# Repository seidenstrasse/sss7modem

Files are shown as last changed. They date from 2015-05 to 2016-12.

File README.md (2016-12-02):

SSS7 Modems
===========
SSS7 is the **S**eidenstrasse **S**ignaling **S**ystem 7.

**This is still work in progress, contact me before building hardware !**

This repository contains the schematics its the hardware,
along with a description of the physical layer and the transport layer.
The actual application layer is developed independently of this project.

Physical Layer
--------------
The physical layer is based on a RS485-like two wire bus
(normal RS485 has different levels when idle),
using the *MCP2551* is used as transceiver chip.
Since this chip is actually a CAN-transceiver,
it has a well defined behaviour in case of collisions
and it allows to read back the bits which were actually on the bus while sending.
For regular RS485 transceivers a collision on the bus results
in one transceiver pulling the bus while the other one pulls it high,
effectively creating a temporary short circuit.
Therefore using a CAN-transceiver is preferable for our bus configuration.

The MCP2551 requires that the levels of the differential data lines are within +-7V
of its ground potential.
This a bit of a problem, since it is not really practical to run an additional wire
along the bus to provide a common ground.
Additionally routers may use power supplies which do not have a floating ground potential
(e.g. a computer power supply).
Connecting the ground rails of two non-floating power supplies will lead to a problems.
Therefore an isolated DC/DC converter is used to provide a floating supply voltage
for the transceiver chip and the data lines are isolated using optocouplers.
Still a common ground potential for all nodes is required for the transceiver chips to work.
This is solved by adding diodes in blocking direction between the floating 5v rail and both data lines
and between the chips ground and both data lines.
If the potential of the high data line is more than 0.7v above the floating 5v rail,
on of diodes will become conducting effectively shifting the floating grounds potential up.
Likewise if the potential of the low data line is more than 0.7v below the floating ground rail,
the ground rail will be shifted down.
Hence the floating grounds rails of all modems connected to bus will be within +-0.7v
relative to each other(not considering the voltage drop over the long wires).

Additionally these diodes suppress voltages spikes on the bus,
protecting the transceiver.

Using a sss7modem any device with a decent UART (microcontroller, raspi ...)
can communicate over long distances (1000m+).
The data is send at 9600 Baud (aka. 9,6kbit/s) with a maximum baudrate error of +-5%,
to ensure that even the slowest microcontroller can participate in the communication.
A slow bitrate also necessary to keep communication and collision detection reliable over longer
distances and allows to use slower (and cheaper) optocouplers.

Transport Layer
---------------

### Frame format:
``` 0xAA 0xFE <payload 16 bytes> <payload crc 1byte> ```

19 bytes total

**Header: 0xAA 0xFE**
- Choosen emperically to help the Uarts to synchronize
- Improves detection of two headers colliding

**CRC-Type: Maxim iButton 8-bit**
Polynomial: x^8 + x^5 + x^4 + 1 (0x8C)
Initial value: 0x0

### Communication Protocol

- **Not final, use with caution**
- Frames are sent using standard RS232 Uarts connected to sss7 modems
- Uarts should be configured to: 9600baud, 8bits, 1 stop bit, no flow-control, no parity
- Every node can send a frame at an arbitrary point in time,
    unless it is currently receiving a frame.
- Collision detection on the sender side is done by reading back each sent byte.
- Collision checking on receiver side, is done by checking the CRC and frame header.
- If a frame has been started and there are no new bytes received for 50ms,
    the frame is considered timed out and all received data can be dropped.
- Incoming messages are stored in a fifo until the application retrieves them.
- The receive fifo has a size of at least 2 messages.
- If the fifo is full all new messages will be dropped until messages are retrieved from the fifo.
    It is up to the application to retrieve message in time.
- Even if sending was successful, there is still a chance that the receiver could not
    receive the frame due to missing buffer space or not enough processing time to react.
    **Important messages should utilize a ack-mechanism.**
- It is up to the application to resend messages in case of a collision/missing ack.

### Planned API
- **Not final, use with caution**
- All calls are non-blocking,
    any real work should be done by ISRs or an eventloop, which is called periodically.

- **sss7_can_send()**

    Checks wether we see the bus as idle.
    Return true iff. we neither are currently receiving a frame
    nor are sending a frame of our own.

- **sss7_send_failed()**

    Checks the send error flag.
    Returns true if the last attempt at sending a frame failed.
    An attempt is considered failed if the Uart reads back a different byte than the byte send out.
    This indicates either a collision or a hardware failure.

- **sss7_send(payload)**

    Constructs a frame around the payload and prepares for sending.
    The actual sending is either done in the ISR or by the eventloop, depending on the platform.
    The frame is completely sent iff. ```sss7_can_send() && !sss7_send_failed()``` holds.

- **sss7_has_received()**

    Returns True iff. the receive fifo contains at least one message.

- **sss7_get_received(payload)**

    Retrieves the oldest message from the receive fifo.
    It is up the application to provide sufficient space in payload.
    Does nothing sss7_has_received() is false.

Licenses
--------

Anything in the folder hardware/libs/smisitoto_eu/ is taken from http://smisioto.no-ip.org/elettronica/kicad/kicad-en.htm
The files are made avaible under the Creative Commons license rev2.5 Attribution-ShareAlike. (see https://creativecommons.org/licenses/by-sa/2.5/)

The Chaos InKL logo is licensed CC BY-NC-SA 3.0.

The seidenstrasse logo and my personal logo are not available under an open license.
Therefore you should ask for permission before using the seidenstrasse logo in derived works.
Also please remove my personal logo if I am not involved in your project.

The schematics and pcb layout files in hardware are released under the *CERN Open Hardware License v1.2*.

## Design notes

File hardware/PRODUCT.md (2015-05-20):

Please inform the following licensors about the type, 
quantity and dates of production of Products you have (had) manufactured:

LongHairedHacker <sebastian(~at~)sebastians-site(~point~)de>

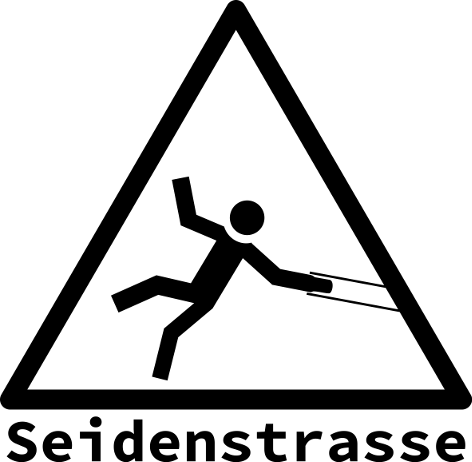
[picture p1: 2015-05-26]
hardware/artwork/seidenstrasse_small.png

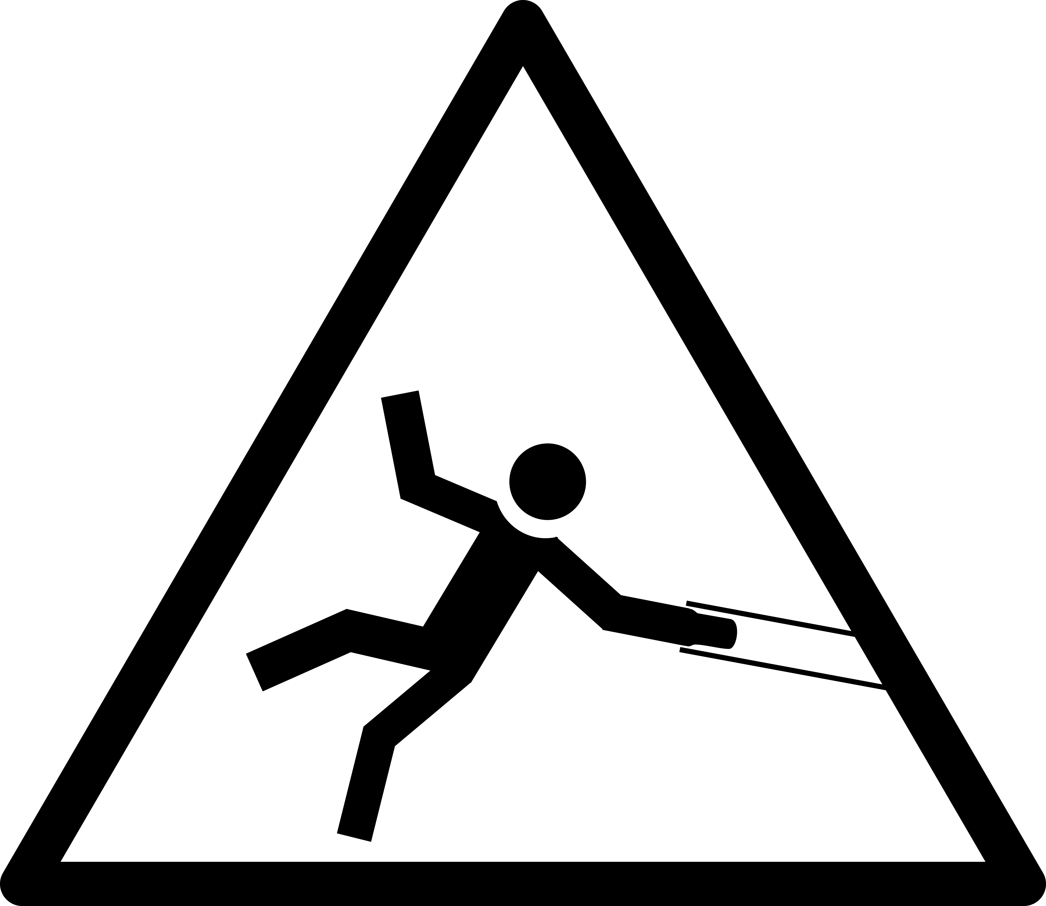
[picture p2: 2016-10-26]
hardware/artwork/seidenstrasse_big.png

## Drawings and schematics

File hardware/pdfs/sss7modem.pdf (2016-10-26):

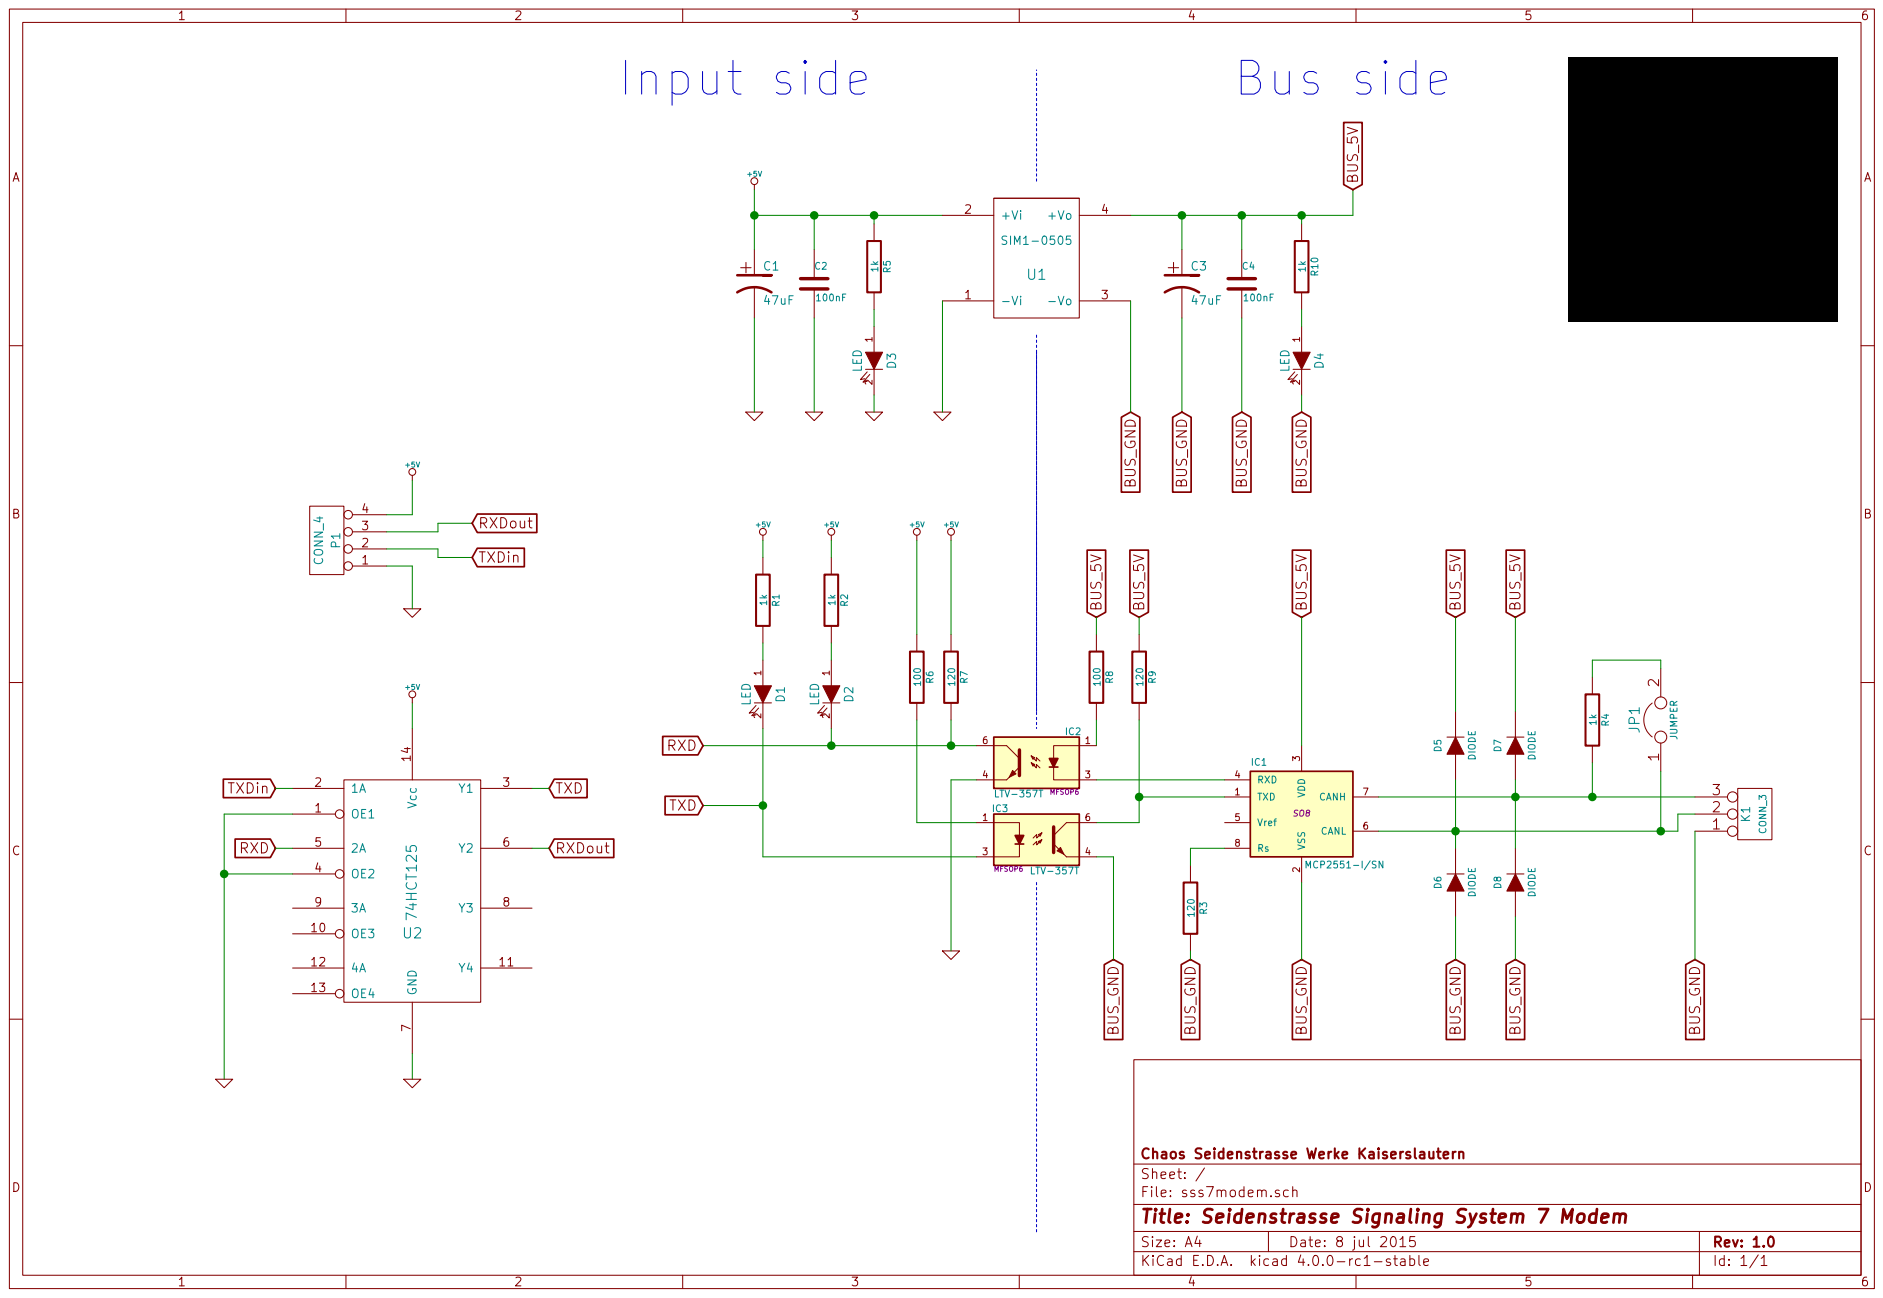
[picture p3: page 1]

3 RXD 4 Vref 5 CANL 6 CANH 7 Rs 8

Id: 1/1 Title: Seidenstrasse Signaling System 7 Modem

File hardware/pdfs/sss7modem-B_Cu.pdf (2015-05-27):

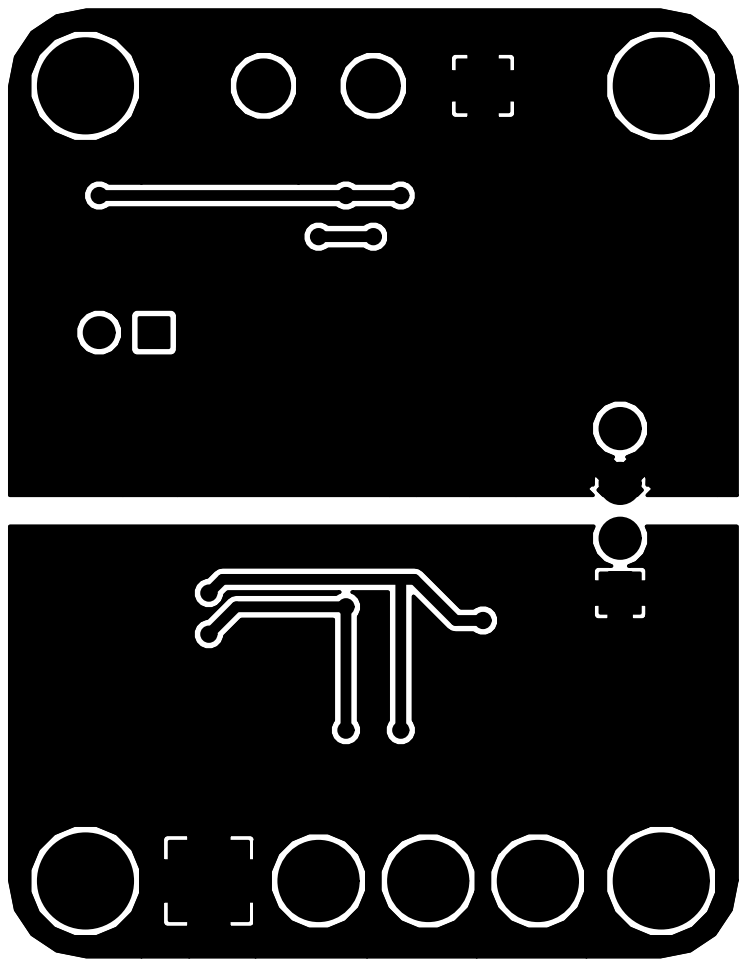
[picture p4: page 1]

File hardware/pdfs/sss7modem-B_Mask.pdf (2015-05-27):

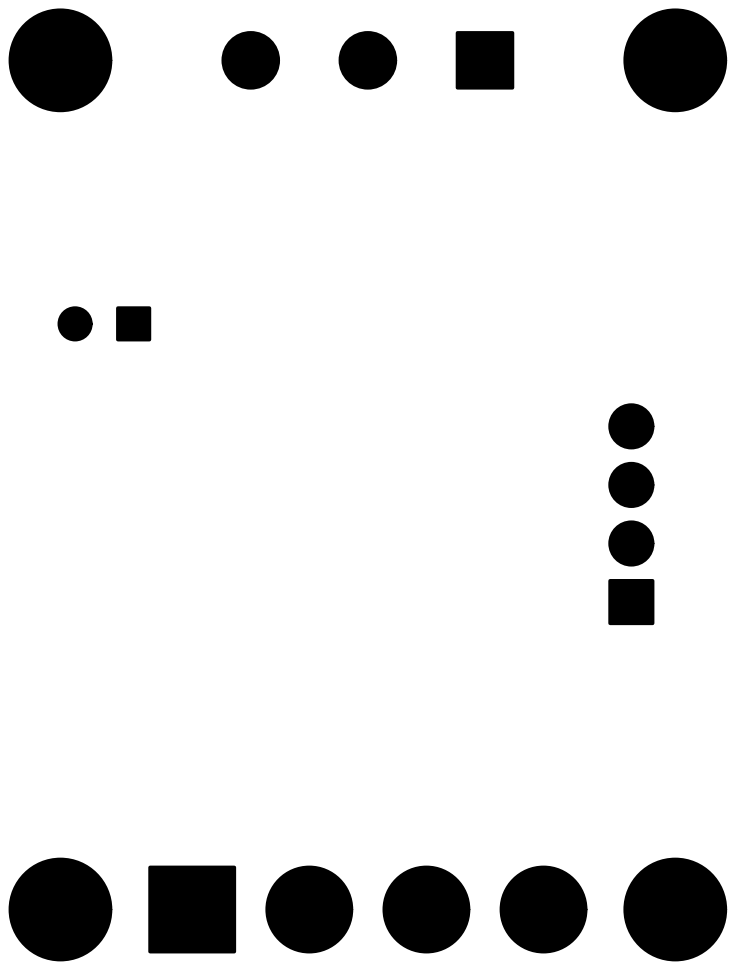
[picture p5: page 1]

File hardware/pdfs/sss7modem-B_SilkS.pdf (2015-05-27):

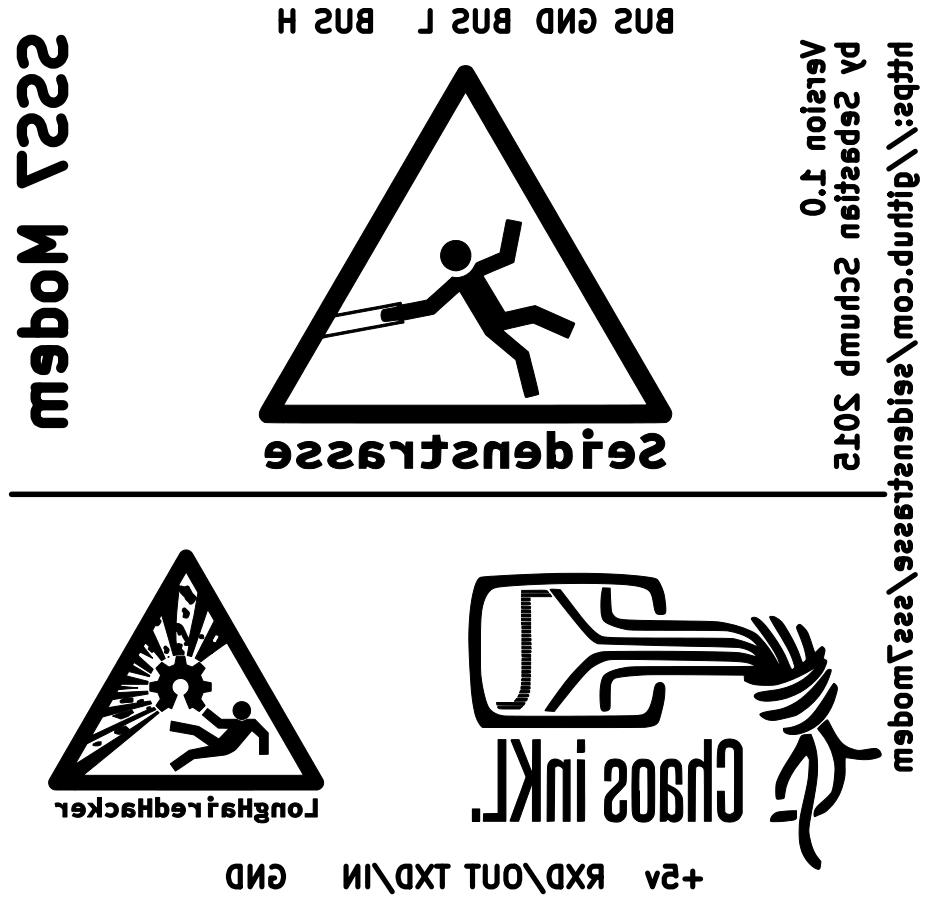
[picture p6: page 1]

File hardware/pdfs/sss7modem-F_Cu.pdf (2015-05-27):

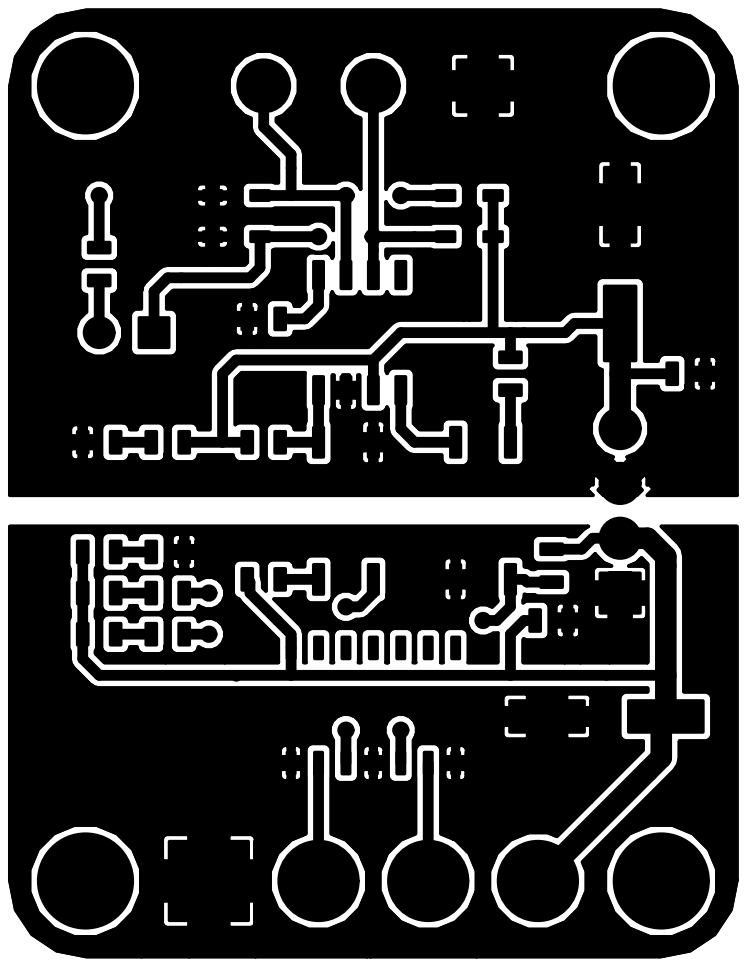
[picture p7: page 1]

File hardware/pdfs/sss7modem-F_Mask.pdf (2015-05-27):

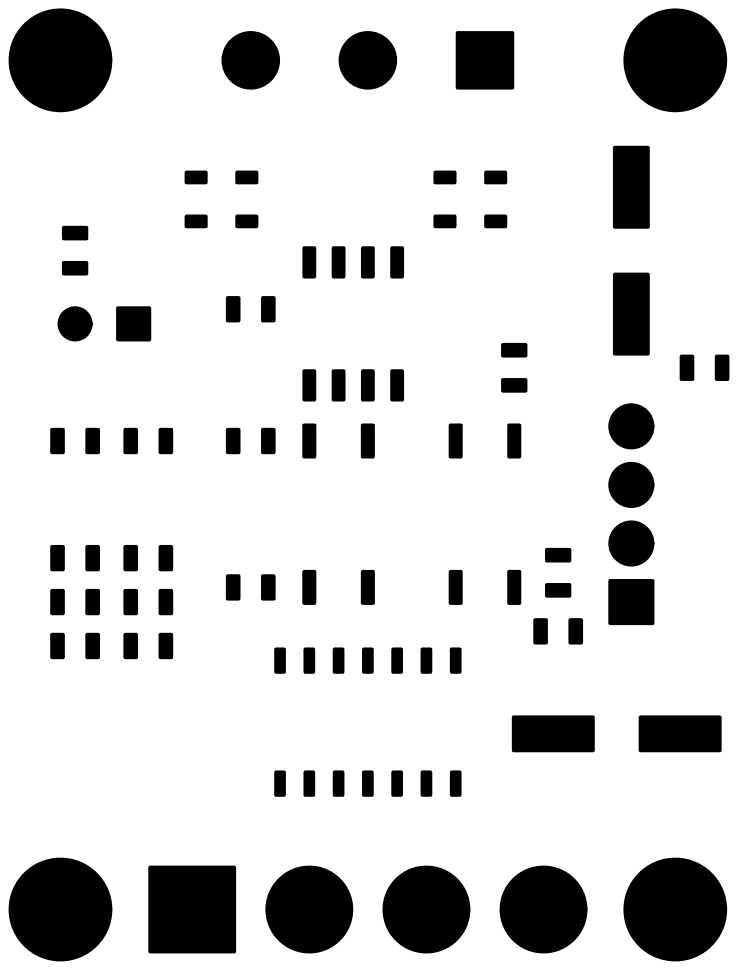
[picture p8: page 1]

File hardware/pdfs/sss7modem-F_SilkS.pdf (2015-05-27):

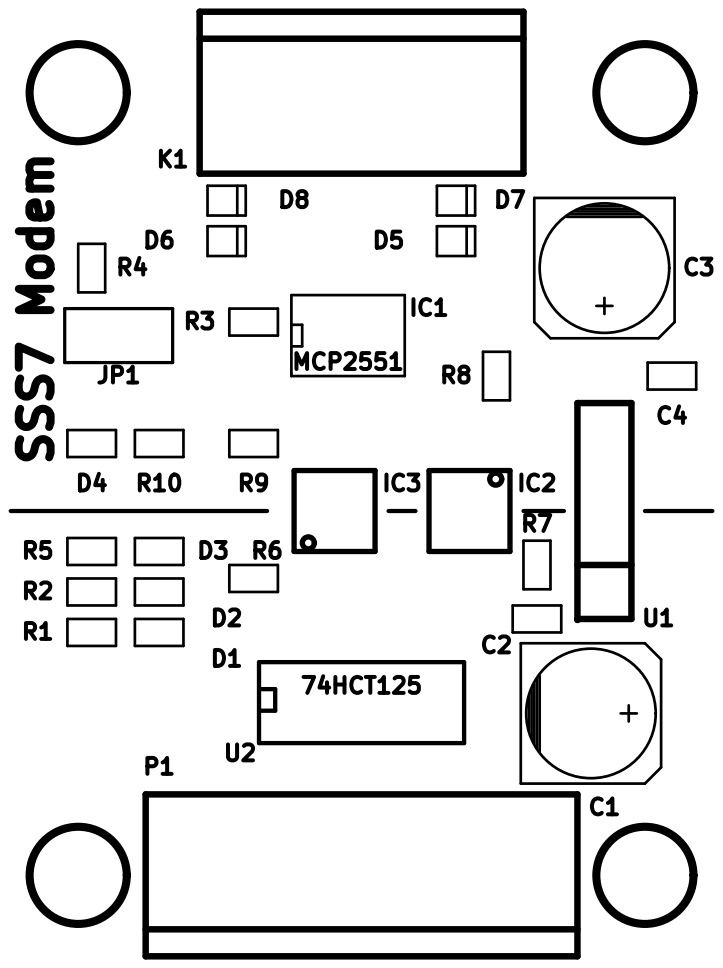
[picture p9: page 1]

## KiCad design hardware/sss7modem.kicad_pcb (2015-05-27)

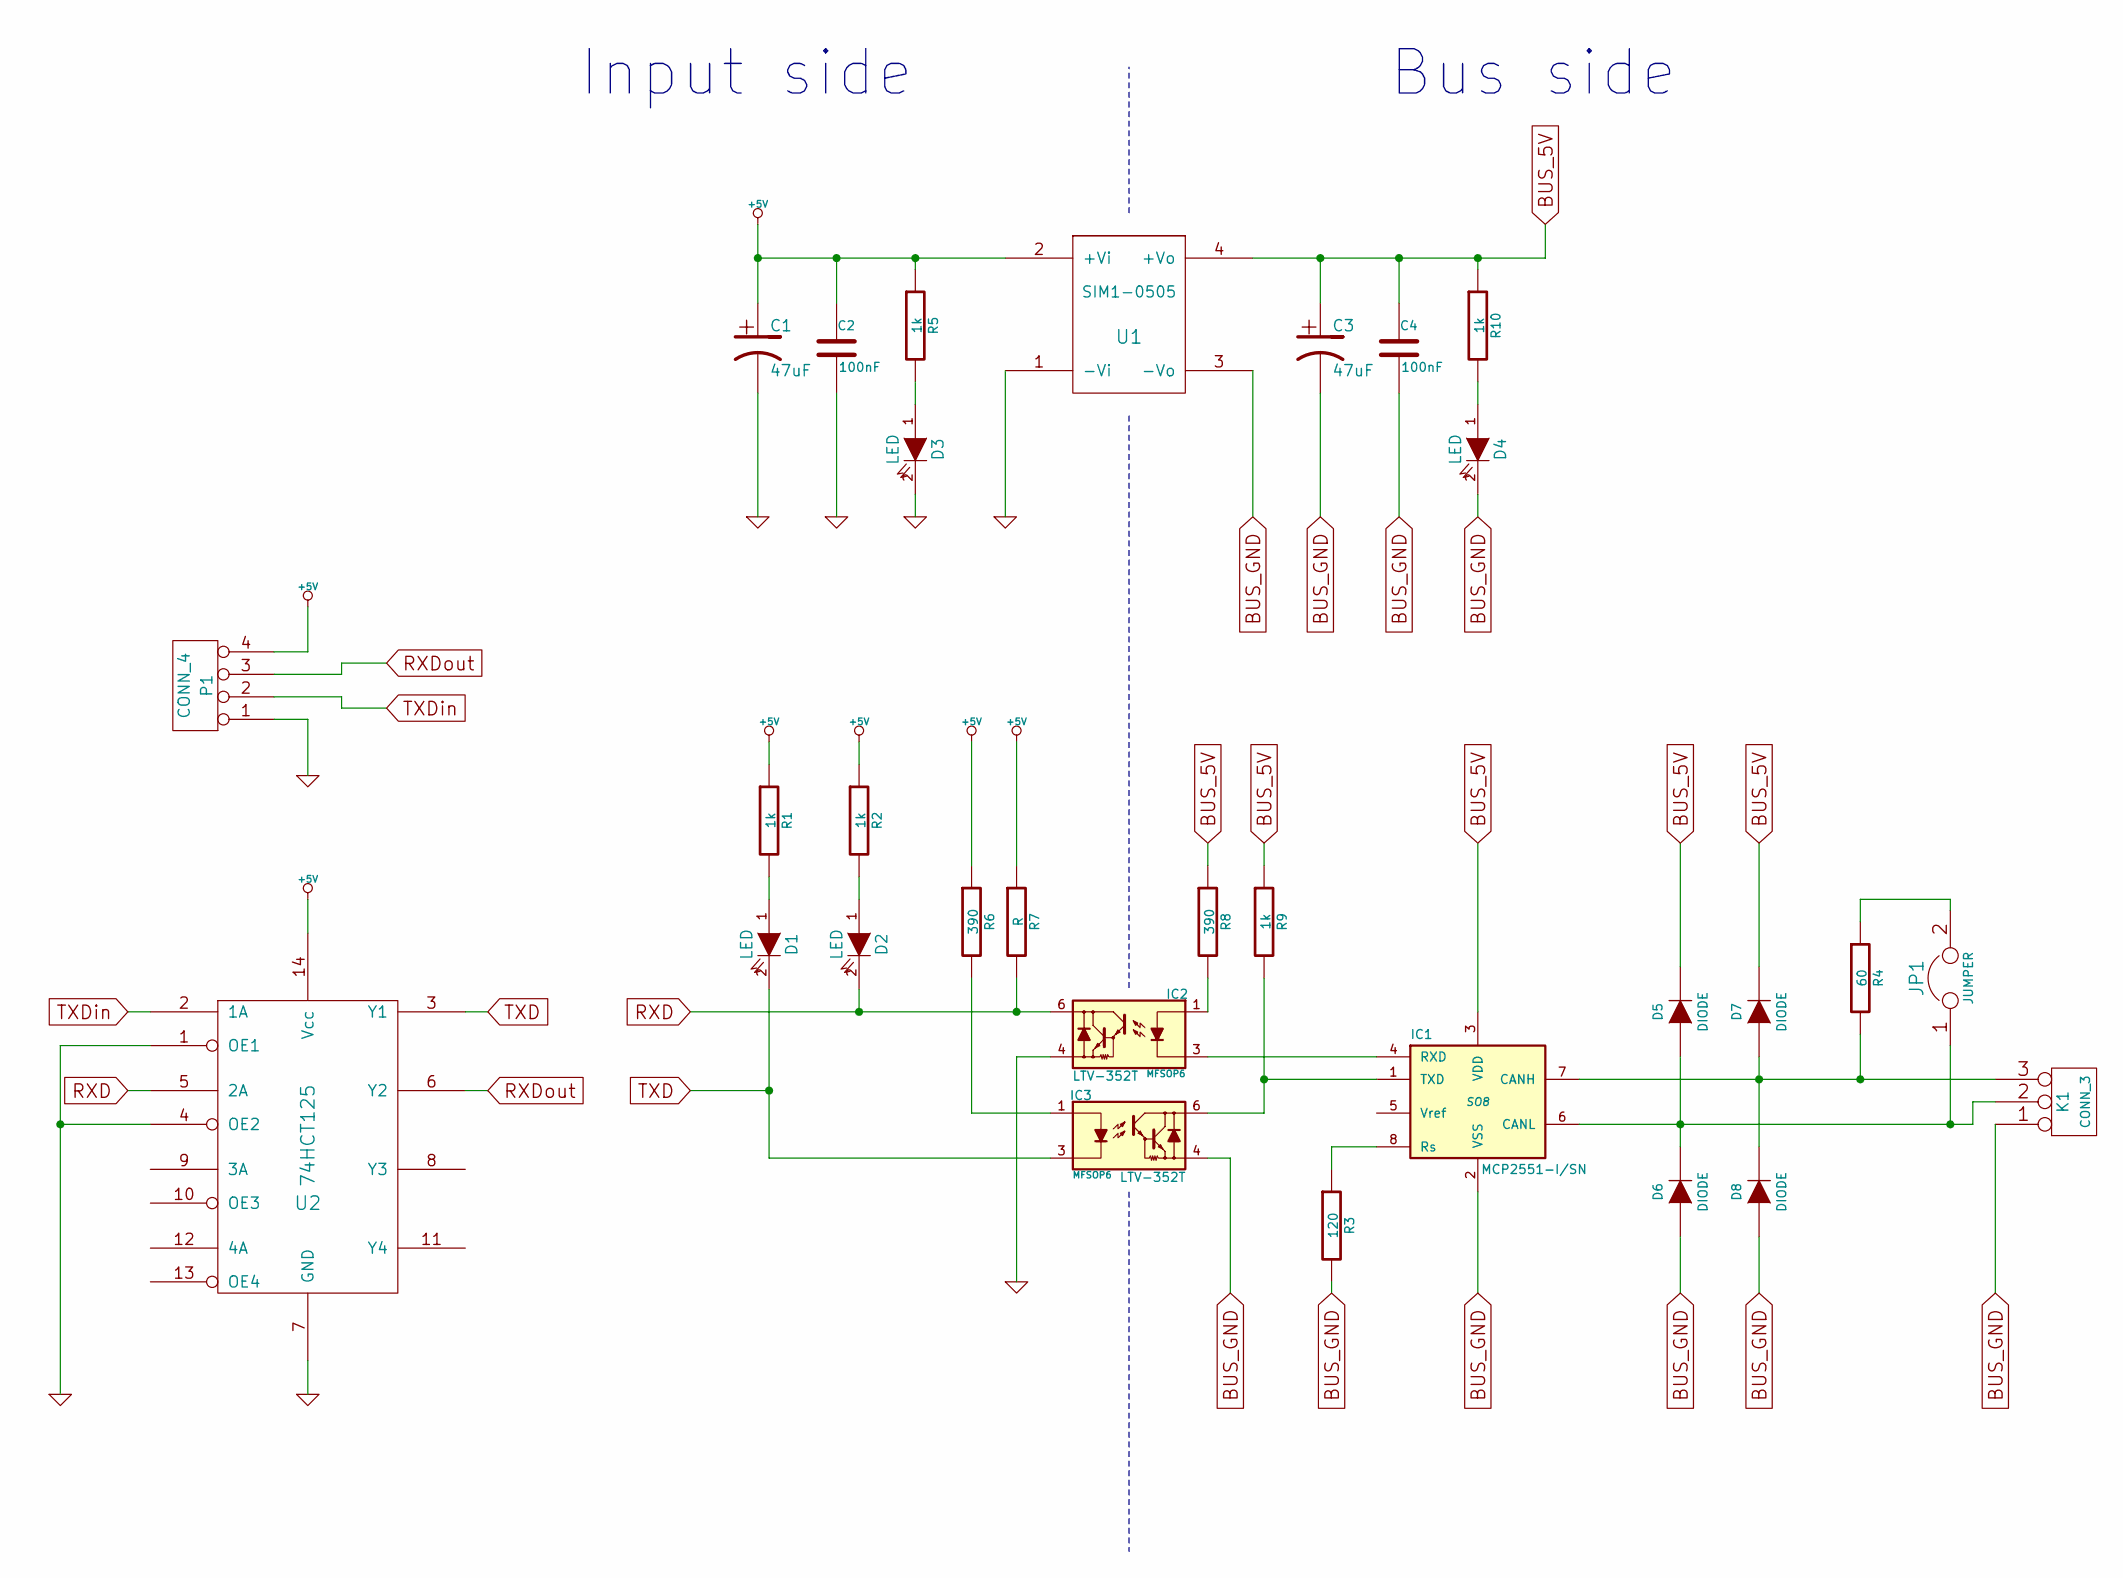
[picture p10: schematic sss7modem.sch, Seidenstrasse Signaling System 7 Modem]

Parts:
C1, C3: 47uF
C2, C4: 100nF
D1, D2, D3, D4: LED
D5, D6, D7, D8: DIODE
IC1: MCP2551-I/SN; SO8
IC2, IC3: LTV-352T; MFSOP6
JP1: JUMPER
K1: CONN_3
P1: CONN_4
R1, R2, R5, R9, R10: 1k
R3: 120
R4: 60
R6, R8: 390
R7: R
U1: SIM1-0505
U2: 74HCT125

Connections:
+5V: C1.1, C2.1, P1.4, R1.1, R2.1, R5.1, R6.1, R7.1, U1.2 (+Vi), U2.14 (Vcc)
BUS_5V: C3.1, C4.1, D5.2 (K), D7.2 (K), IC1.3 (VDD), R8.1, R9.1, R10.1, U1.4 (+Vo)
BUS_GND: C3.2, C4.2, D4.2 (K), D6.1 (A), D8.1 (A), IC1.2 (VSS), IC3.4, K1.1, R3.2, U1.3 (-Vo)
GND: C1.2, C2.2, D3.2 (K), IC2.4, P1.1, U1.1 (-Vi), U2.1 (OE1), U2.4 (OE2), U2.7 (GND)
unnamed: IC3.1, R6.2
unnamed: D2.1 (A), R2.2
unnamed: D1.1 (A), R1.2
unnamed: D4.1 (A), R10.2
unnamed: D3.1 (A), R5.2
unnamed: IC1.1 (TXD), IC3.6, R9.2
unnamed: IC1.4 (RXD), IC2.3
unnamed: IC2.1, R8.2
unnamed: JP1.2, R4.1
unnamed: D7.1 (A), D8.2 (K), IC1.7 (CANH), K1.3, R4.2
unnamed: D5.1 (A), D6.2 (K), IC1.6 (CANL), JP1.1, K1.2 (PM)
unnamed: IC1.8 (Rs), R3.1
RXD: D2.2 (K), IC2.6, R7.2, U2.5 (2A)
RXDout: P1.3, U2.6 (Y2)
TXD: D1.2 (K), IC3.3, U2.3 (Y1)
TXDin: P1.2, U2.2 (1A)

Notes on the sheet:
Bus side
Input side

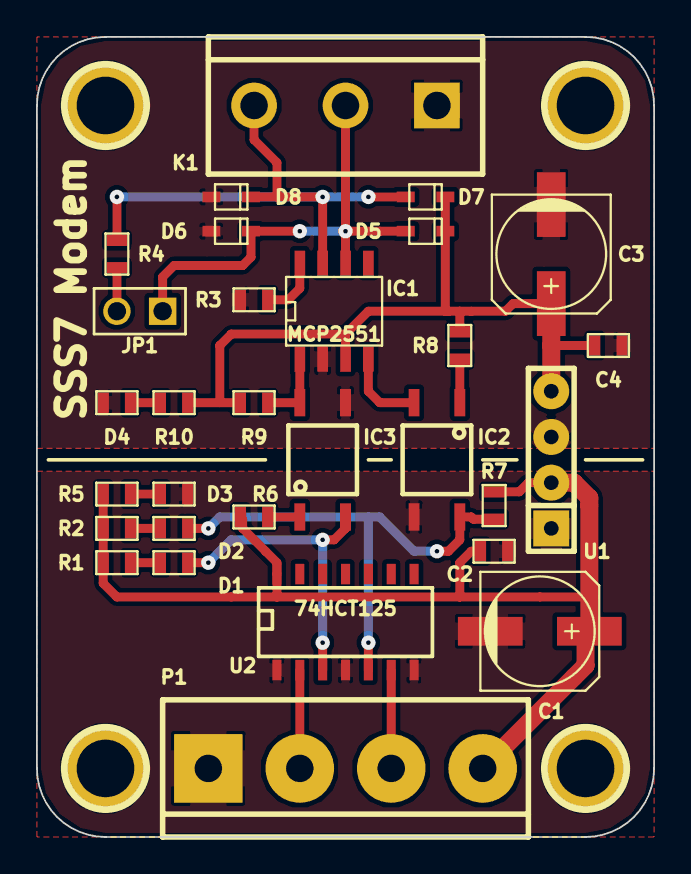
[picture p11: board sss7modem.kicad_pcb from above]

Board: 2 copper layers, 34.3 x 44.4 mm, 34 parts (0 on the bottom side), 20 nets.

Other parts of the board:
1PIN, 1PIN#2, 1PIN#3, 1PIN#4: P***; 1pin

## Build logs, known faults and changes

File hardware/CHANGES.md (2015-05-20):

Changes
=======

LongHairedHacker
----------------
Initial Design

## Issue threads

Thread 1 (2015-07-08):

Optocouplers are to slow

LongHairedHacker, 2015-07-08:
Using 1k as resistors as pullups (R7, R9) at the transistor side of the LTV-352 does not provide enough current to the darlington arrangement to switch fast enough.

Also the rise time of the LTV-352 is to high.
With a 60Ohm pullup the rise time is still about 41us,
whereas at 9600Baud a single bit is only about 100us wide.

The yellow signal is the TXD signal of SSS7 modem and the blue one is the RXD signal,
showing the same bit being read back from the bus.

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

The timing difference between the two rising edges is about 41us.

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

For the falling edges the difference is only about 12us.

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

The datasheet of for the LTV-352 specifies between 100us and 500us maximum rise time depending on the load resistance.

The current setup works for ft232rl as uart since these chips are very tolerant regarding baudrate errors.
Still this is not the ideal solution.  Faster optocouplers with the same footprint would be preferable.

LongHairedHacker, 2015-08-06:
As a side note: The delays cause by the old optocoupler make it impossible to use AVR uarts.

LongHairedHacker, 2015-11-06:
Using LTV-356 and changing the led current limit resistor to 100Ohm and the Phototransistor pullup to 120Ohm it is possible to achieve a delay of about 8us for falling and rising edges.

This should be okay, since as long as the delay for falling and rising edges stays the same,
high and low bits will keep the same length.

Closed 2015-07-08.

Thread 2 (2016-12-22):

sss7_send_failed() is broken

LongHairedHacker, 2016-12-22:
Calling sss7_send_failed() will give false results in some cases even.

The reason for this is that the state is set to IDLE directly after **sss7_process_tx** sends the crc byte.
Therefore a second thread polling **sss7_can_send** will receive a true before the crc byte has been read back and verified in **sss7_process_rx**.
Also **sss7_process_rx** will not perform collision checks on the byte since we are back in IDLE state.
In the call of **sss7_process_tx** that follows, the missing result of the collision check will lead to the failed flag being set regardless of the current state.

On AVR the sss7_can_send becomes true in between  **sss7_process_rx**  and **sss7_process_tx**,
when the failed flag has not been set yet,
therefore any transmission that was able to send all byte prior to the crc byte seemed successful.

On other platforms  the result of **sss7_send_failed** depends on a race condition between the polling thread and the event loop thread.
If the polling thread calls  **sss7_send_failed** before the final **sss7_process_tx** the failed flag will appear not set, otherwise it will always be set.

This happens regardless of any real collision on the bus.

Closed 2016-12-22.

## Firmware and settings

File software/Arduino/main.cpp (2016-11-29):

#include <Arduino.h>
#include "ardusss7.h"

void setup() {
	Serial.begin(9600);

	Serial.print("Initializing SSS7...");
	SSS7.init();
	Serial.println("Done !");

};


void loop() {
	uint8_t msg[SSS7_PAYLOAD_SIZE];
    memset(msg, 0, SSS7_PAYLOAD_SIZE);
    msg[0] = 'H';
    msg[1] = 'e';
    msg[2] = 'l';
    msg[3] = 'l';
    msg[4] = 'o';
    msg[5] = ' ';
    msg[6] = 'W';
    msg[7] = 'o';
    msg[8] = 'r';
    msg[9] = 'l';
    msg[10] = 'd';


    while(1) {
		Serial.println("Waiting to send");
        while(!SSS7.canSend());
		Serial.println("Sending ...");
        SSS7.send(msg);
        while(!SSS7.canSend());
		//Serial.println("Finished Sending");
        if(SSS7.sendFailed()) {
            Serial.println("Send failed");
        }


		if(SSS7.hasReceived()) {
			uint8_t msg1[SSS7_PAYLOAD_SIZE];
			SSS7.getReceived(msg1);
			Serial.print("Got data:");
			Serial.println((char*)msg1);
		}

        _delay_ms(1000);
    }

};

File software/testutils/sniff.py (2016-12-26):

#!/usr/bin/env python2

import sys
import serial
import crcmod.predefined


def hexdump(data):
    res = ""
    for char in data:
        res += "%X " % (ord(char))

    return res



def main():
    if len(sys.argv) != 2:
        print "Usage %s <port>" % (sys.argv[0])
        sys.exit(-1)

    ser = serial.Serial(sys.argv[1], 9600, timeout=0.40)
    ser.reset_input_buffer()


    while True:
        data = ser.read(19)
        while data == "":
            data = ser.read(19)

        if len(data) != 19:
            print "No Frame:\t" + hexdump(data)
            continue


        header_ok = data.startswith(chr(0xAA) + chr(0xFE))


        line = ""
        if header_ok:
            line += "Header Ok       "
        else:
            line += "Header not Ok   "

        payload = data[2:18]
        crc = crcmod.predefined.Crc('crc-8-maxim')
        crc.update(payload)
        crc_sum = crc.digest()
        if data[18] == crc_sum:
            line += "CRC Ok      "
        else:
            line += "CRC not Ok  "

        line += hexdump(payload)
        print line


if __name__ == '__main__':
    main()

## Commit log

2015-05-21 Changed schematic for floating common on bus side
    [sss7modem.kicad_pcb, sss7modem.sch]
2015-05-21 Added a pdf so others can take a look as well
    [sss7modem.sch]
2015-05-22 First draft for the split ground pcb
    [sss7modem.kicad_pcb, sss7modem.sch]
2015-05-25 Made boards smaller for panalizing
    [sss7modem.kicad_pcb]
2015-05-26 Added logos, started to clean up silkscreen
    [sss7modem.kicad_pcb, sss7modem.sch]
2015-05-27 Update readme to explain the common ground problem
2015-05-27 Finalized pcb layout and silkscreen
    [sss7modem.kicad_pcb, sss7modem.sch]
2015-05-27 Generated gerbers
    [sss7modem-B_Cu.gbl, sss7modem-B_Mask.gbs, sss7modem-B_SilkS.gbo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]
2015-06-02 Added bounding box to workaround bugs in the panelizer tool
    [sss7modem-B_Cu.gbl, sss7modem-B_Mask.gbs, sss7modem-B_SilkS.gbo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]
2015-06-02 In retrospective this did not make anything better Revert "Added bounding box to workaround bugs in the panelizer tool"
    This reverts commit c11f25827b3cbd9794efebe66123eeaa10cdf22c.
    [sss7modem-B_Cu.gbl, sss7modem-B_Mask.gbs, sss7modem-B_SilkS.gbo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]
2015-06-26 Added missing resistor value
    [sss7modem.sch]
2015-06-26 Cleaned up control flow
2015-06-28 Added preamble to frames
2015-07-08 Changes optocouplers to something faster. fixes #1
    [sss7modem.sch]
2015-11-06 Fixed resistor values
    [sss7modem.sch]
2016-10-26 Adjusted termination resistor and rebuild gerbers
    [sss7modem-B_Cu.gbl, sss7modem-B_Mask.gbs, sss7modem-B_SilkS.gbo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]
2016-10-28 Fixed tx_failed flag not being reset Fixed makefile
    [main.c, sss7.c]
2016-10-29 Added test util for sending frames Adjusted timeouts for slow uarts
2016-10-30 Fixed rx buffer behaviour Fixed bytes being swapped in error message
    [main.c, send.py, sss7.c]
2016-11-20 Fixed sniffer crashing on timeout
    [sniff.py]
2016-11-21 Uart part of arduino wrapper done
2016-11-21 Added timer code for timeouts
2016-11-21 Enabled timeout timer
2016-11-26 Added a makefile to compile with Arduino libraries Added a extern "C" to sss7.h
2016-11-26 Switched to UART2 as UART1 does not work on my board Tested sending and Timeouts, looks good so far
    [ardusss7.cpp, ardusss7.h, main.cpp]
2016-11-26 Fixed sniff.py for fragments
    [sniff.py]
2016-11-26 Fixed timeout timers
2016-11-30 Added threads and mutexes for eventloop
2016-12-04 Fixed debug output Added better test
    [libsss7.c]
2016-12-19 Added synchronized to become thread-safe Added README
2016-12-20 added real stuff maybe wrong place to commit (sorry)
    [main.cpp]
2016-12-22 Totally the wrong place Revert "added real stuff maybe wrong place to commit (sorry)"
    This reverts commit ba4616e152fde6ce86b764eb18ae483fef601afb.
    [main.cpp]
2016-12-22 Added SSS7_TX_FINALIZE state Fixes #2
    [sss7.c]
2017-12-27 Added some fixes for c++ compatebility
    [libsss7.c]
